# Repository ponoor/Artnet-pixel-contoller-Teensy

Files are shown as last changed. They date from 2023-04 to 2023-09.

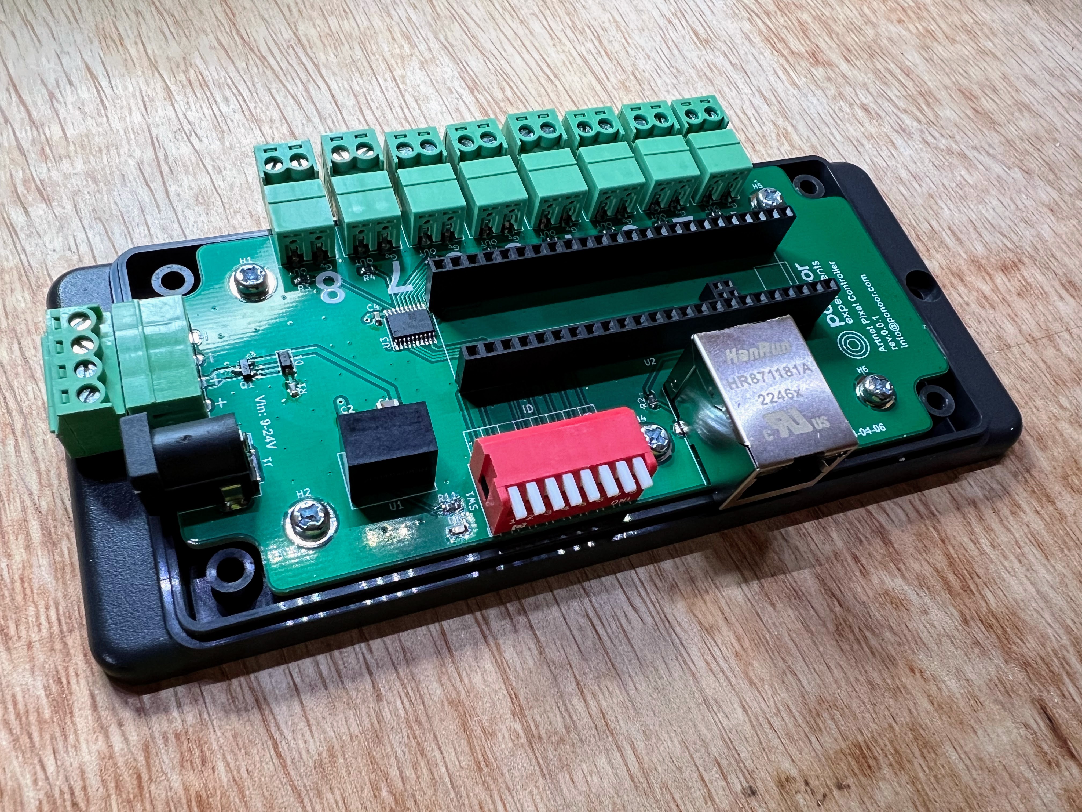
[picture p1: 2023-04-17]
Artnet_pixel_controller_Teensy-hardware/production_data/prototype_Assembled.jpg

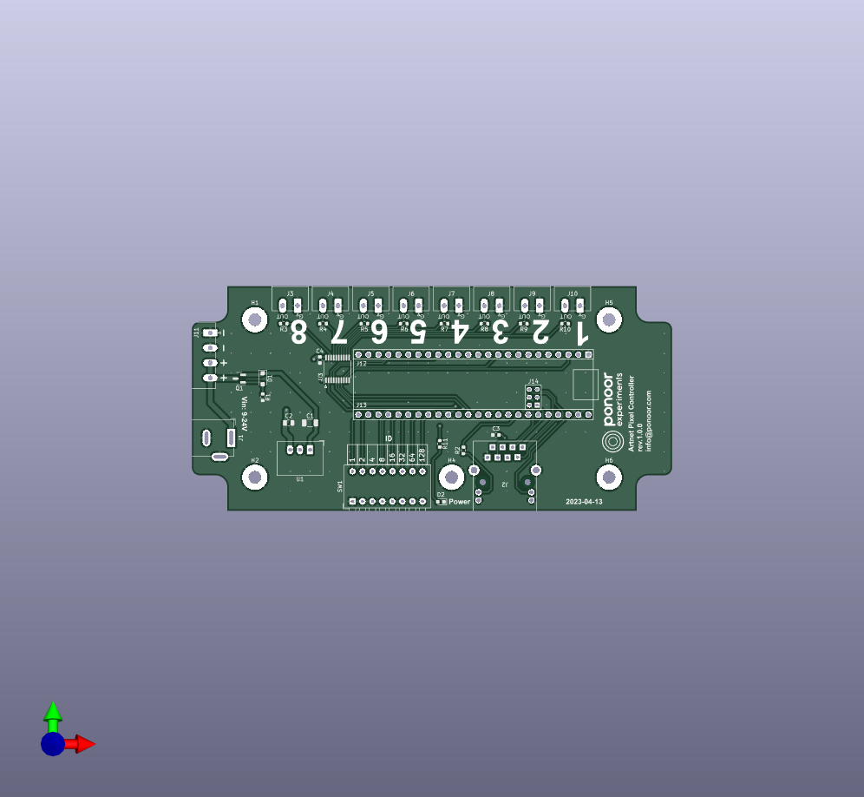
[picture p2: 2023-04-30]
Artnet_pixel_controller_Teensy-hardware/Artnet_pixel_controller_Teensy-hardware.png

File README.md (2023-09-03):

# Artnet-pixel-contoller-Teensy
A simple addressable LED controller with Art-Net.

We choose Teensy4.1 to reduce components around Ethernet. It is bit too luxury for this application but still much cheaper than serious commercial pixel controllers.

- Firmware by niimi
- Hardware by kanta



<!--
<img src="https://github.com/ponoor/Artnet-pixel-contoller-Teensy/assets/1097902/cb70d5fd-e741-4c89-b13c-3c2e43a0f1bb" width="40%" /><img src="https://github.com/ponoor/Artnet-pixel-contoller-Teensy/assets/1097902/271e32cb-7cf3-4a00-a239-2e03ac957660" width="40%" />
-->



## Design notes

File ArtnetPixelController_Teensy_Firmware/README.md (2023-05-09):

# デバイス設定項目
- network
    - ip i i i i
    - gateway i i i i
    - subnet i i i i
    - mac i i i i i i
    - ipAddId i(b)
    - macAddId i(b)
- artnet
    - port i
    - net i
    - subnet i
    - universe i
- osc
    - dstPort i
    - dstIp i i i i
    - srcPort i
    - dstPortAddId i(b)
- led
    - numPixels i
    - protocol i
    - colorOrder i
    - initTest i(b)
## デバイス設定のOSC送り方
/config/network/ip 10 0 0 0
のように送ると値を保存してリセット後に適応される
## colorOrderとは
```
OctoWS2811.h:39
#define WS2811_RGB	0	// The WS2811 datasheet documents this way
#define WS2811_RBG	1
#define WS2811_GRB	2	// Most LED strips are wired this way
#define WS2811_GBR	3
#define WS2811_BRG	4
#define WS2811_BGR	5
```
## protocolとは
```
OctoWS2811.h:70
#define WS2811_800kHz 0x00	// Nearly all WS2811 are 800 kHz
#define WS2811_400kHz 0x40	// Adafruit's Flora Pixels
#define WS2813_800kHz 0x80	// WS2813 are close to 800 kHz but has 300 us frame set delay
```
# その他OSCコマンド
## /rst
リセットする。シリアルをつなげてると起動しないxx
## /print
シリアルにconfigの値を出力する
## /ping
/pongをかえす
## /setDstIp
oscの送信先アドレスをすぐに変えるが保存はされない
## /ledTest
r g b

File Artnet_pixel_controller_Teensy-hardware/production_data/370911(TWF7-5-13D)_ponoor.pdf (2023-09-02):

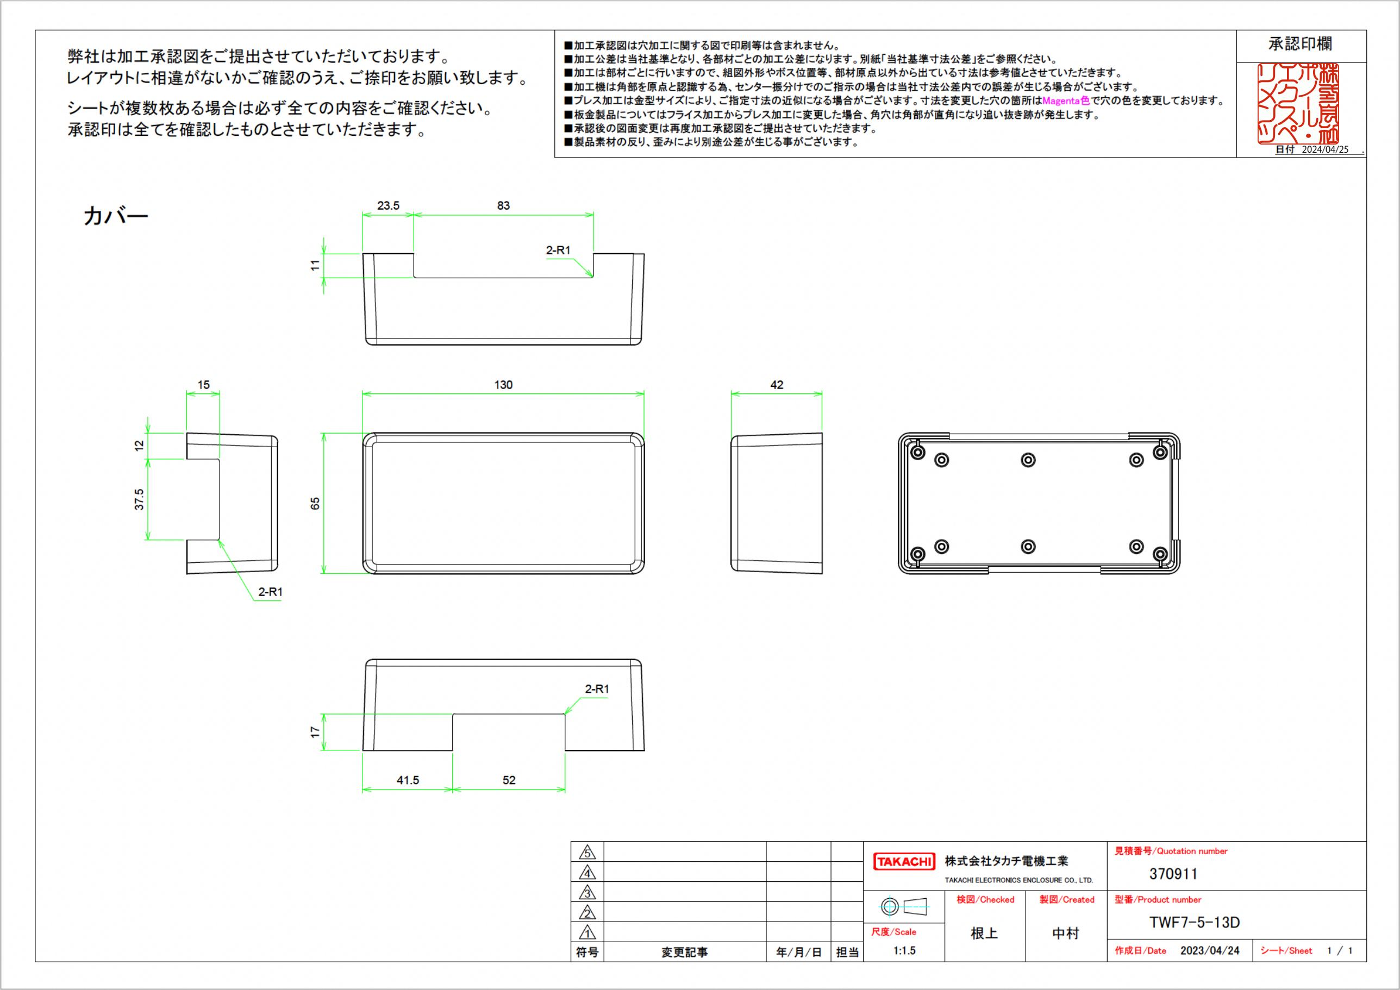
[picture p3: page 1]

2024/04/25

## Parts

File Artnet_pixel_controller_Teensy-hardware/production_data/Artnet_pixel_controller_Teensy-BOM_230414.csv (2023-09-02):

# | Name | Value | Description | Package | Manufacture | MPN | Qty | Ref | SMT | THT
1 | MLCC | 10uF/50V | 10uF / 20% / 50V / X5R | C1206 | Samsung Electro-Mechanics | CL31A106KBHNNNE | 1 | C1 | 1
2 | MLCC | 10uF/10V | 10uF / 20% / 10V / X5R | C0805 | Samsung Electro-Mechanics | CL21A106KOQNNNG | 1 | C2 | 1
3 | MLCC | 100nF/50V | 100nF / 20% / 50V / X5R | C0603 | Walsin Tech Corp | 0603B104K500CT | 2 | C3, C4 | 2
4 | Zener Diode | 5.1V | 350mW 5.1V | SOD-123F | Jiangsu Changjing Electronics Technology Co., Ltd. | BZT52C5V1 | 1 | D1 | 1
5 | LED | Green | general LED green | LED0603 | Everlight Elec | 19-213/GHC-YR1S2M/3T | 1 | D2 | 1
6 | DC Barrel Jack | DC Power receptacle | 5A 2.0mm 6.2mm | Connector_BarrelJack:BarrelJack_GCT_DCJ200-10-A_Horizontal | XKB Connectivity | DC-005-5A-2.0 | 1 | J1 |  | 1
7 | RJ45 Jack with Magnetics | HR871181A |  | HR871181A | Hanrun | HR871181A | 1 | J2 |  | 1
8 | 3.81mm connector | 2 Pins | 3.81mm Pluggable System Terminal Block | Push-Pull,P=3.81mm | Ningbo Kangnex Elec | WJ15EDGRC-3.81-2P | 8 | J3, J4, J5, J6, J7, J8, J9, J10 |  | 8
9 | 3.81mm connector | 4 Pins | 3.81mm Pluggable System Terminal Block | Push-Pull,P=3.81mm | Ningbo Kangnex Elec | WJ15EDGRC-3.81-4P | 1 | J11 |  | 1
10 | Female Headers |  | Straight 1x24P 8.5mm Top 24 Square Holes | P=2.54mm | XKB Connectivity | X6511FV-24-C85D32 | 2 | J12, J13 |  | 2
11 | Female Headers |  | Straight 2x3P 4.3mm Top 6 Square Holes | P=2mm | HCTL | PM200-2-03-Z-4.3 | 1 | J14 |  | 1
12 | P-MOSFET | AO3401A | 30V 4.4A | SOT-23 | Yangzhou Yangjie Elec Tech | YJL3401A | 1 | Q1 | 1
13 | Resistor | 10k | 5% 1/10W | R0603 | YAGEO | RC0603JR-0710KL | 2 | R1, R11 | 2
14 | Resistor | 220 | 5% 1/10W | R0603 | YAGEO | RC0603JR-07220RL | 1 | R2 | 1
15 | Resistor | 470 | 5% 1/10W | R0603 | YAGEO | RC0603JR-07470RL | 8 | R3, R4, R5, R6, R7, R8, R9, R10 | 8
16 | DIP Switches | 8P, Side Sw | SPST Red Piano 8 keys DIP Switches | DIP16 | Cixi Tonver Elec | VPG/S-08HG-R | 1 | SW1 |  | 1
17 | Power Modules | 5V 500mA | 6.5V~36V input DC-DC |  | MORNSUN Guangzhou S& T | K7805-500R3 | 1 | U1 |  | 1
18 | Octal BUS Transceivers, 3-State outputs | 74HC245 | Buffer/Driver/Transceiver | TSSOP-20 | Wuxi I-core Elec | AiP74HCT245TA20.TR | 1 | U3 | 1
 |  |  |  |  |  | SUM: | 35 |  | 19 | 16

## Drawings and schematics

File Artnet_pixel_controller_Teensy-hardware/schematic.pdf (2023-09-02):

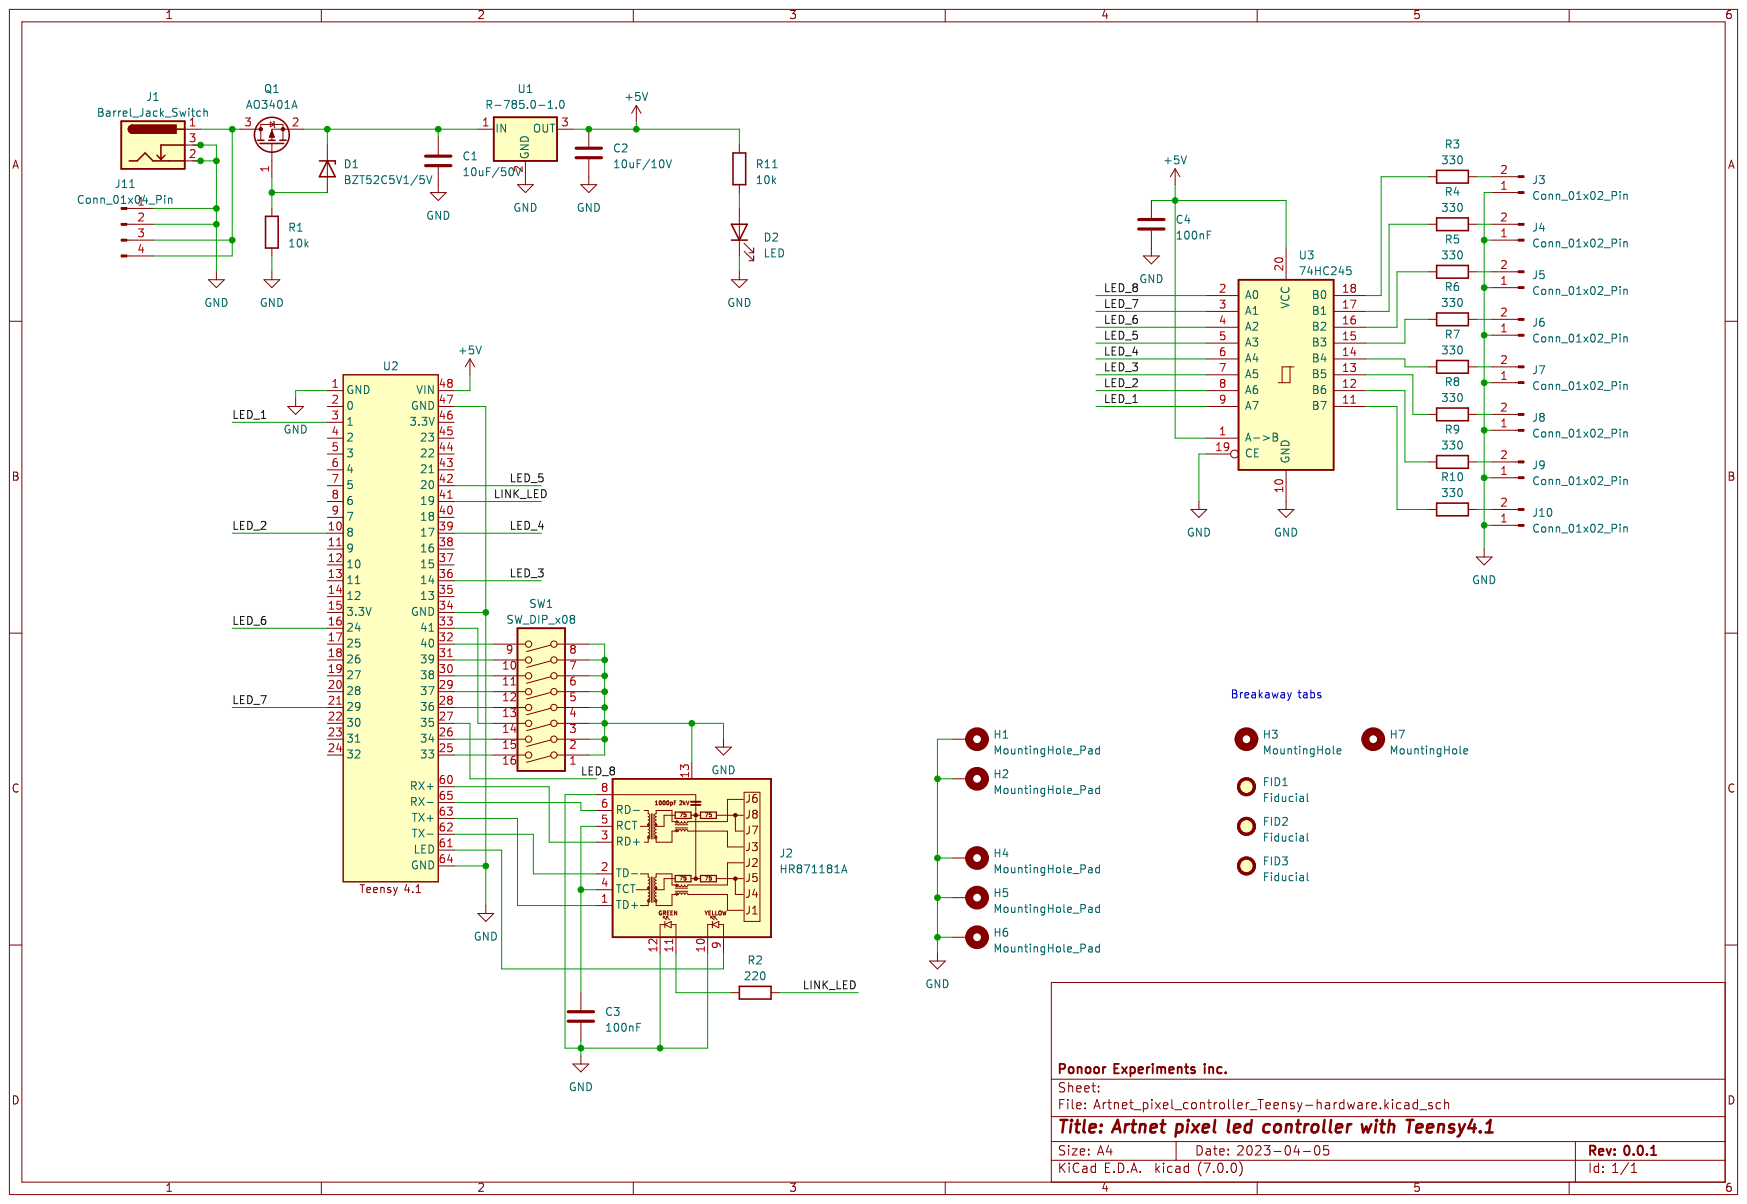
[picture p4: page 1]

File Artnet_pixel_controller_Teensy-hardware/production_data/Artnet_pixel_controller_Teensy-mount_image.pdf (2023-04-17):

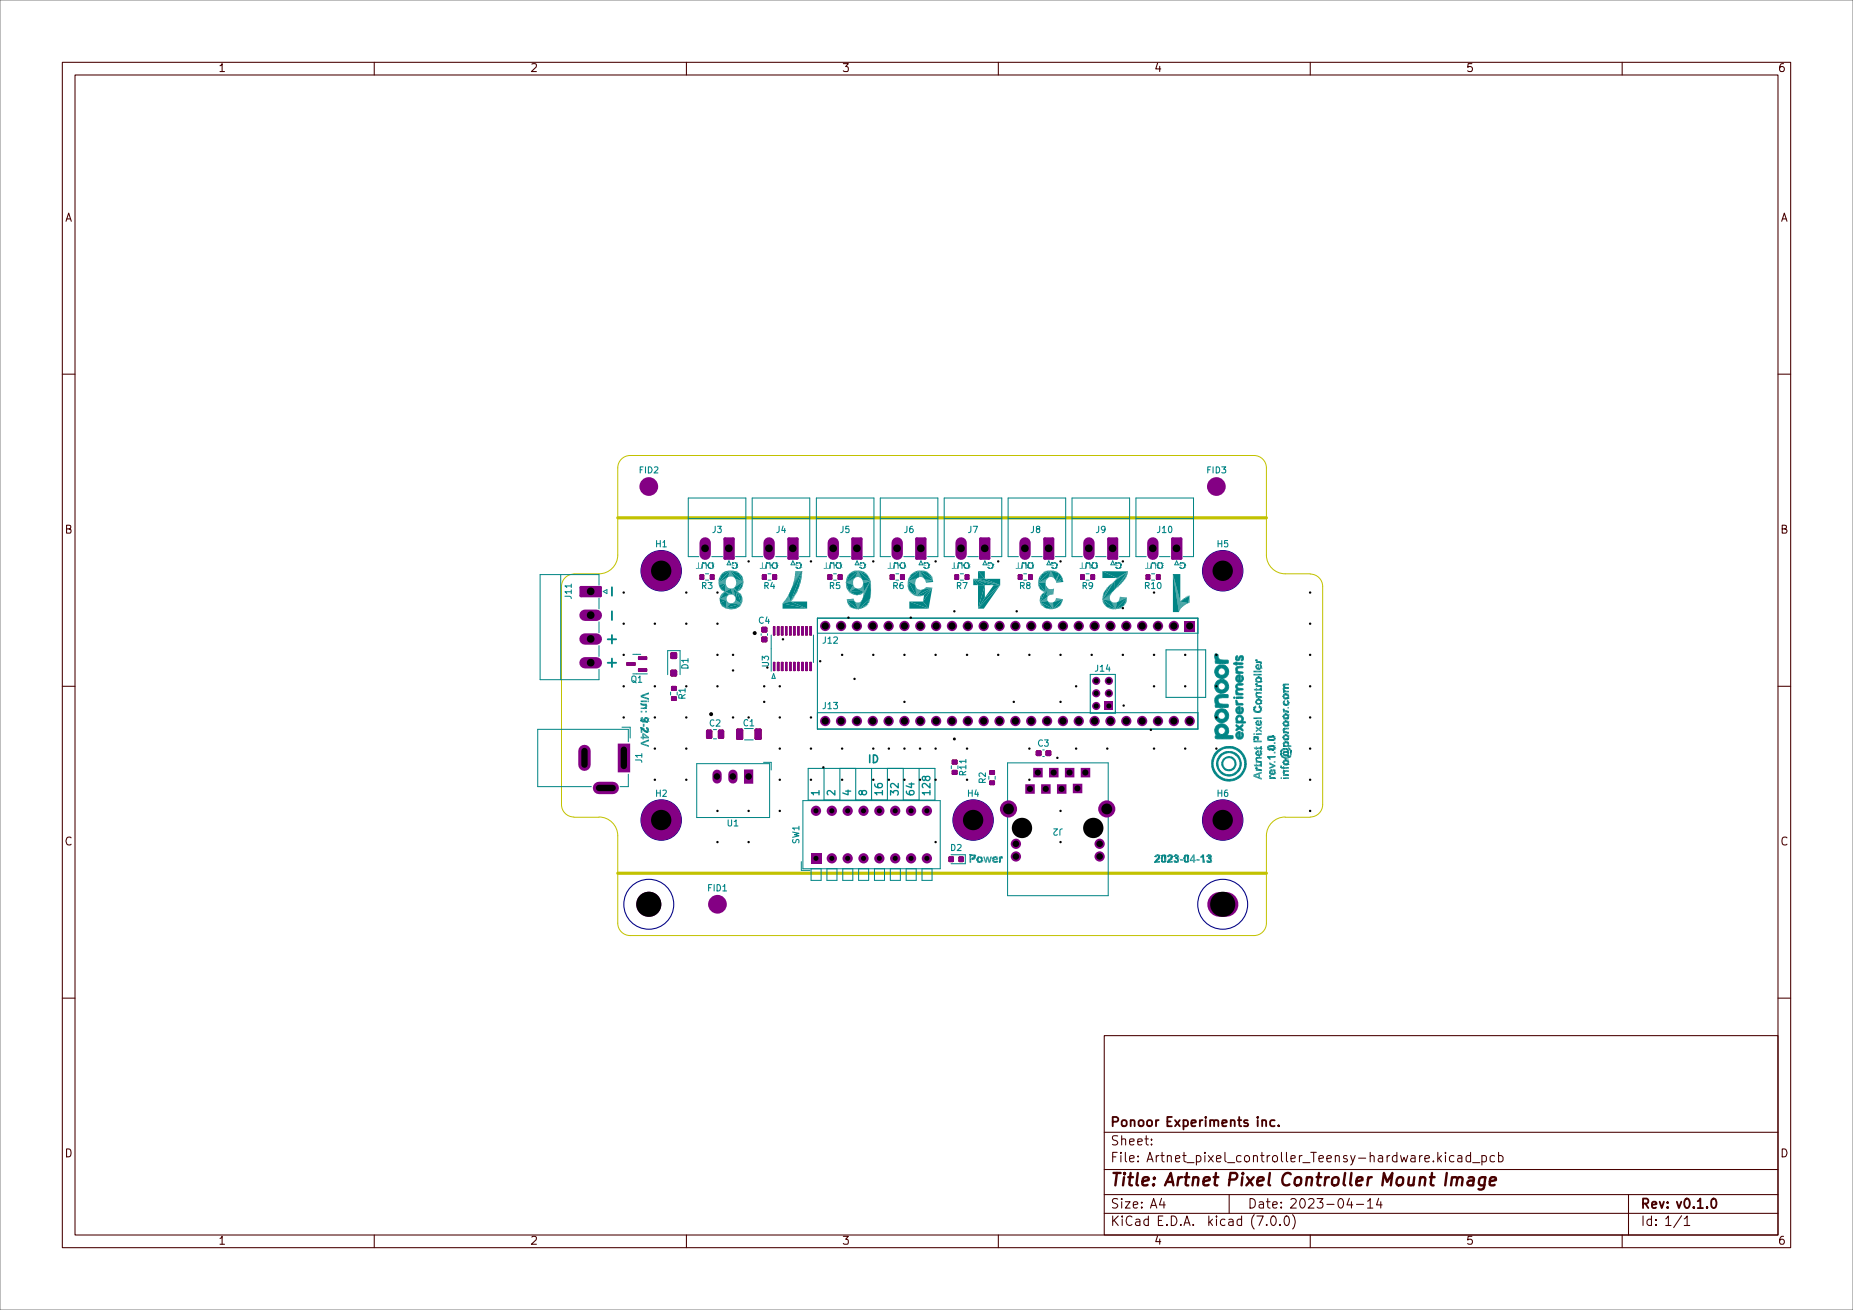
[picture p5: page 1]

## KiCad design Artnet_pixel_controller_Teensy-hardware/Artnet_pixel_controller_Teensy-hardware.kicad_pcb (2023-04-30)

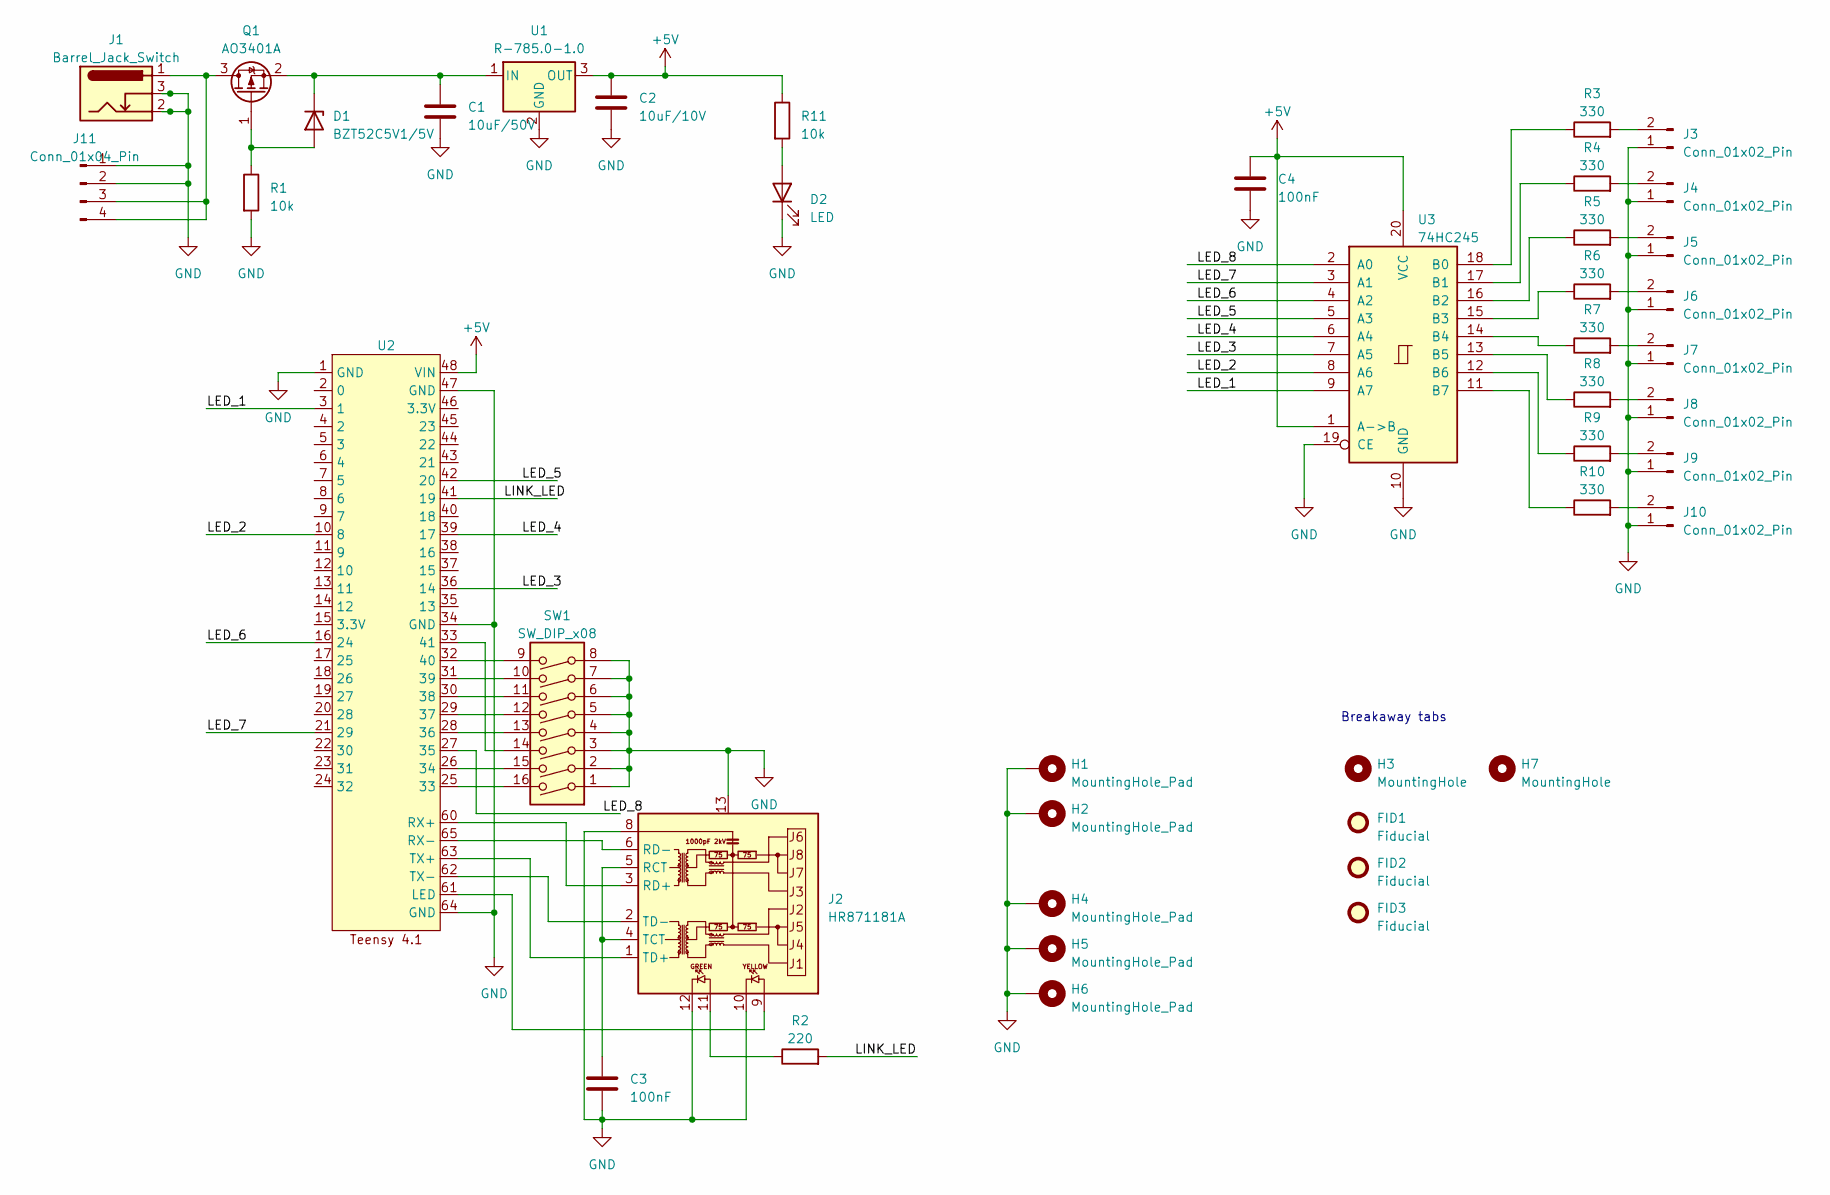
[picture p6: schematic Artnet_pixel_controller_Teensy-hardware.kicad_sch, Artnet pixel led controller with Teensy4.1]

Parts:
C1: 10uF/50V; C_1206_3216Metric
C2: 10uF/10V; C_0805_2012Metric
C3, C4: 100nF; C_0603_1608Metric
D1: BZT52C5V1/5V; D_SOD-123F
D2: LED; LED_0603_1608Metric
FID1, FID2, FID3: Fiducial; Fiducial_1mm_Mask3mm
H1, H2, H4, H5, H6: MountingHole_Pad; MountingHole_3.2mm_M3_Pad
H3, H7: MountingHole; MountingHole_4mm
J1: Barrel_Jack_Switch; BarrelJack_GCT_DCJ200-10-A_Horizontal
J2: HR871181A
J3, J4, J5, J6, J7, J8, J9, J10: Conn_01x02_Pin; PhoenixContact_MC_1,5_2-G-3.81_1x02_P3.81mm_Horizontal
J11: Conn_01x04_Pin; PhoenixContact_MC_1,5_4-G-3.81_1x04_P3.81mm_Horizontal
Q1: AO3401A; SOT-23
R1, R11: 10k; R_0603_1608Metric
R2: 220; R_0603_1608Metric
R3, R4, R5, R6, R7, R8, R9, R10: 330; R_0603_1608Metric
SW1: SW_DIP_x08; SW_DIP_SPSTx08_Piano_10.8x21.88mm_W7.62mm_P2.54mm
U1: R-785.0-1.0; Converter_DCDC_RECOM_R-78E-0.5_THT
U2: Teensy41_bothside+ETH
U3: 74HC245; TSSOP-20_4.4x6.5mm_P0.65mm

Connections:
+5V: C2.1, C4.1, R11.1, U1.3 (OUT), U2.48 (VIN), U3.1 (A->B), U3.20 (VCC)
/LED_1: U2.3 (1), U3.9 (A7)
/LED_2: U2.10 (8), U3.8 (A6)
/LED_3: U2.36 (14), U3.7 (A5)
/LED_4: U2.39 (17), U3.6 (A4)
/LED_5: U2.42 (20), U3.5 (A3)
/LED_6: U2.16 (24), U3.4 (A2)
/LED_7: U2.21 (29), U3.3 (A1)
/LED_8: U2.27 (35), U3.2 (A0)
/LINK_LED: R2.2, U2.41 (19)
GND: C1.2, C2.2, C3.2, C4.2, D2.1 (K), H1.1, H2.1, H4.1, H5.1, H6.1, J1.2, J1.3, J2.8, J2.10, J2.12, J2.13, J3.1, J4.1, J5.1, J6.1, J7.1, J8.1, J9.1, J10.1, J11.1, J11.2, R1.2, SW1.1, SW1.2, SW1.3, SW1.4, SW1.5, SW1.6, SW1.7, SW1.8, U1.2 (GND), U2.1 (GND), U2.34 (GND), U2.47 (GND), U2.64 (GND), U3.10 (GND), U3.19 (CE); also elsewhere on the board
unnamed: D1.2 (A), Q1.1 (G), R1.1
unnamed: C1.1, D1.1 (K), Q1.2 (S), U1.1 (IN)
unnamed: D2.2 (A), R11.2
unnamed: J2.11, R2.1
unnamed: C3.1, J2.4 (TCT), J2.5 (RCT)
unnamed: J2.3 (RD+), U2.60 (RX+)
unnamed: J2.6 (RD-), U2.65 (RX-)
unnamed: J2.1 (TD+), U2.63 (TX+)
unnamed: J2.2 (TD-), U2.62 (TX-)
unnamed: J3.2, R3.2
unnamed: J4.2, R4.2
unnamed: J5.2, R5.2
unnamed: J6.2, R6.2
unnamed: J7.2, R7.2
unnamed: J8.2, R8.2
unnamed: J9.2, R9.2
unnamed: J10.2, R10.2
unnamed: J1.1, J11.3, J11.4, Q1.3 (D)
unnamed: SW1.16, U2.25 (33)
unnamed: SW1.15, U2.26 (34)
unnamed: SW1.13, U2.28 (36)
unnamed: SW1.12, U2.29 (37)
unnamed: SW1.11, U2.30 (38)
unnamed: SW1.10, U2.31 (39)
unnamed: SW1.9, U2.32 (40)
unnamed: SW1.14, U2.33 (41)
unnamed: J2.9, U2.61 (LED)
unnamed: R3.1, U3.18 (B0)
unnamed: R4.1, U3.17 (B1)
unnamed: R5.1, U3.16 (B2)
unnamed: R6.1, U3.15 (B3)
unnamed: R7.1, U3.14 (B4)
unnamed: R8.1, U3.13 (B5)
unnamed: R9.1, U3.12 (B6)
unnamed: R10.1, U3.11 (B7)

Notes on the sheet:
Breakaway tabs

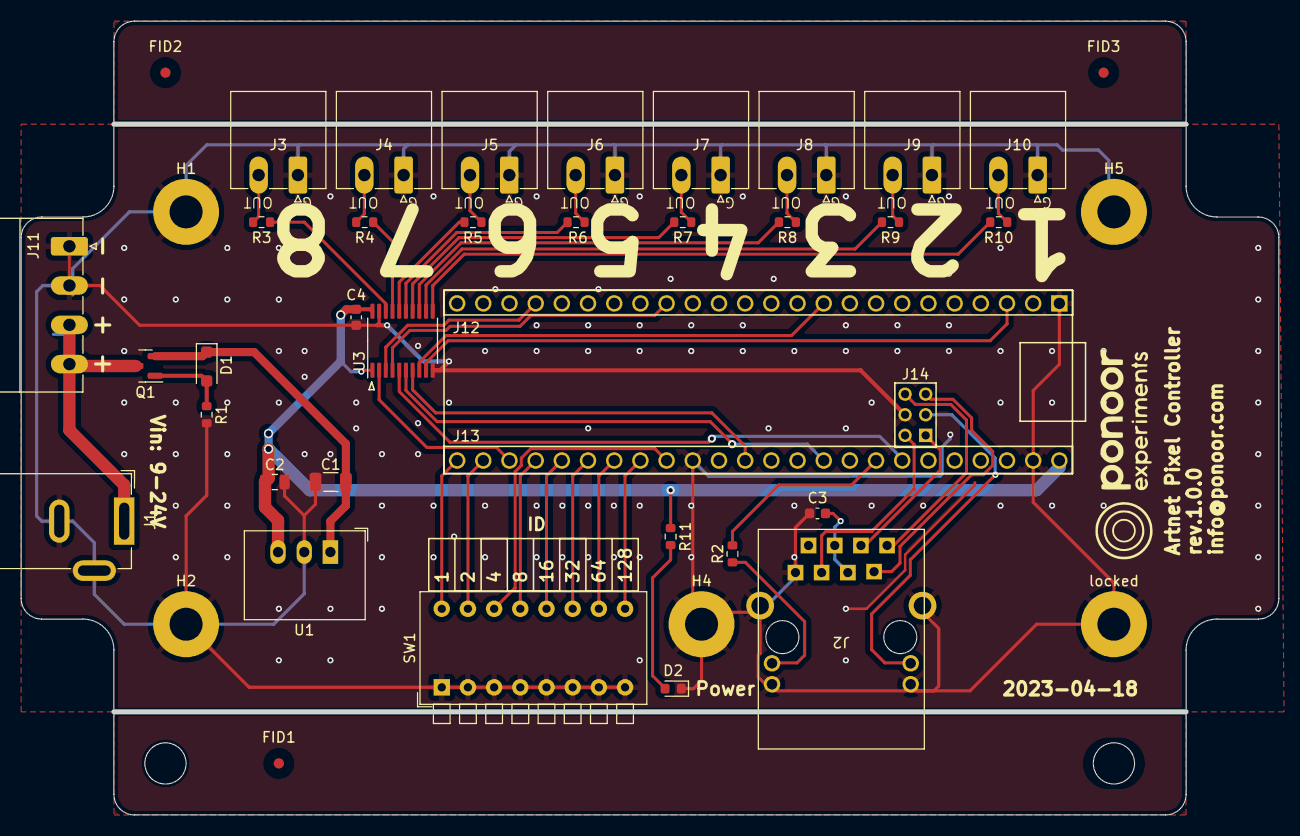
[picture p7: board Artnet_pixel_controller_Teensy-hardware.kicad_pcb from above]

Board: 2 copper layers, 122.0 x 77.0 mm, 43 parts (0 on the bottom side), 46 nets.

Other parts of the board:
locked: MountingHole_Pad; MountingHole_3.2mm_M3_Pad

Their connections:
GND: locked.1; also elsewhere on the board

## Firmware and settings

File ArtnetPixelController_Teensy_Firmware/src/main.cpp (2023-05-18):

#include <Arduino.h>

#include <NativeEthernet.h>
#include <NativeEthernetUdp.h>

#include "ApcConfig.h"
#include "ApcId.h"
#include "ApcArtnet.h"
#include "ApcOsc.h"
// #include "ApcLed.h"
#include "ApcLedSerial.h"

// #define RESTART_ADDR       0xE000ED0C
// #define READ_RESTART()     (*(volatile uint32_t *)RESTART_ADDR)
// #define WRITE_RESTART(val) ((*(volatile uint32_t *)RESTART_ADDR) = (val))

void convertFromJson(JsonVariantConst src, IPAddress& dst) {
  dst.fromString(src.as<const char*>());
}
bool canConvertFromJson(JsonVariantConst src, IPAddress& dst) {
  return dst.fromString(src.as<const char*>());
}
apc::Config config;
apc::Id id;
apc::Artnet artnet;
apc::Osc osc;
apc::LedSerial led;

void onDmxFrame(uint16_t universe, uint16_t length, uint8_t sequence,
                uint8_t* data, IPAddress remoteIP);
void onSync(IPAddress remoteIP);
void onNonSync();

void onReceiveRst();
void onReceiveLedTest();
void onReceivePrint();
void onReceiveClearConfig();
void onReceiveConfigInt(const char* category, const char* name, int value);
void onReceiveConfigIntArray(const char* category, const char* name, int* value, size_t size);
void onReceiveConfigIpaddress(const char* category, const char* name, IPAddress value);

void printDeviceSetting();
void printIp(const char* name, IPAddress ip);

uint8_t universePerStrip;
bool bSerialOpen = false;
bool bLink = false;
void setup() {
    Serial.begin(115200);
    // while (! Serial); 
    delay(1000);
    Serial.println("program start");
    pinMode(apc::variables::linkPin, OUTPUT);

    config.init(0, 1024);
    id.init();

    uint8_t deviceId = id.getId();

    uint8_t mac[6];
    for (auto i = 0; i < 6; i ++) {
        mac[i] = config.json["network"]["mac"][i];
    }
    if (config.json["network"]["macAddId"].as<bool>()) {
        mac[5] += deviceId;
    }
    IPAddress ip = config.json["network"]["ip"];
    if (config.json["network"]["ipAddId"].as<bool>()) {
        ip[3] += deviceId;
    }

    Ethernet.begin(
        mac,
        ip, 
        config.json["network"]["gateway"], 
        config.json["network"]["gateway"], 
        config.json["network"]["subnet"]);

    universePerStrip = ceil(config.json["led"]["numPixels"].as<uint16_t>() / 170.0f);
    
    artnet.init(config.json["artnet"]["port"], 
        ip,
        config.json["network"]["subnet"],
        config.json["artnet"]["net"], 
        config.json["artnet"]["subnet"], 
        config.json["artnet"]["universe"],
        config.json["artnet"]["fps"],
        (bool)config.json["artnet"]["foceSync"]);
    
    artnet.setArtDmxCallback(onDmxFrame);
    artnet.setArtSyncCallback(onSync);
    artnet.setNonSyncCallback(onNonSync);

    int dstPort = config.json["osc"]["dstPort"];
    if (config.json["osc"]["dstPortAddId"]) {
        dstPort += deviceId;
    }
    osc.init(config.json["osc"]["srcPort"], config.json["osc"]["dstIp"], dstPort);
    osc.setRstCallback(onReceiveRst);
    osc.setPrintCallback(onReceivePrint);
    osc.setClearConfigCallback(onReceiveClearConfig);
    osc.setLedTestCallback(onReceiveLedTest);
    osc.setConfigCallbackInt(onReceiveConfigInt);
    osc.setConfigCallbackIntArray(onReceiveConfigIntArray);
    osc.setConfigCallbackIpaddress(onReceiveConfigIpaddress);

    led.init(
        (int)config.json["led"]["numPixels"],
        (uint8_t)config.json["led"]["colorOrder"],
        (uint8_t)config.json["led"]["protocol"]);
    
    if (config.json["led"]["initTest"].as<bool>()) {
        led.initTest();
    }
}

void loop() {
    artnet.update();
    osc.update();

    if(Ethernet.linkStatus() == LinkON) {
        if (!bLink) {
            bLink = true;
            digitalWrite(apc::variables::linkPin, HIGH);
        }
    } else {
        if (bLink) {
            bLink = false;
            digitalWrite(apc::variables::linkPin, LOW);
        }
    }

    if (Serial) {
        if (!bSerialOpen) {
            bSerialOpen = true;
            printDeviceSetting();
        }
    } else {
        if (bSerialOpen) {
            bSerialOpen = false;
        }
    }
    // put your main code here, to run repeatedly:
}

// uint32_t dmxTimestamp = 0;
// uint32_t syncTimestamp = 0;

void onDmxFrame(
    uint16_t universe, 
    uint16_t length, 
    uint8_t sequence,
    uint8_t* data, 
    IPAddress remoteIP) {

    uint8_t stripIndex = universe / universePerStrip;
    uint8_t universeIndex = universe % universePerStrip;

    // Serial.printf("on dmx frame: {uni: %d, len: %d, seq: %d}\n", universe, length, sequence);
    // Serial.print(", strip index: ");
    // Serial.print(stripIndex);
    // Serial.print(", univIndex: ");
    // Serial.print(universeIndex);
    // Serial.println("}");
    
    led.setPixels(stripIndex, universeIndex * 170, data, length);
    // if (universe == 0) {
    //     uint32_t now = millis();
    //     Serial.printf("dmx time: %d, delta: %d\t", now, now - dmxTimestamp);
    //     dmxTimestamp = now;
    // }
}
//on dmx frame: { uni: 31, len: 512, strip index: 7, univIndex: 3}
void onSync(IPAddress remoteIP) { 
    // Serial.println("on sync: ");
    led.show();
    // uint32_t now = millis();
    // Serial.printf("sync time: %d, delta: %d\n", now, now - syncTimestamp);
    // syncTimestamp = now;
}
void onNonSync() {
    led.show();
}

void onReceiveRst() {
    // _restart_Teensyduino_();
    // WRITE_RESTART(0x5FA0004);
    // SCB_AIRCR = 0x05FA0004;
    SCB_AIRCR = 0x05FA0004;
    asm volatile ("dsb");
    // asm volatile ("BKPT 254");
}
void onReceiveLedTest() {
    led.initTest();
}
void onReceivePrint() {
    printDeviceSetting();
}
void onReceiveClearConfig() {
    config.clear();
}
void onReceiveConfigInt(const char* category, const char* name, int value) {
    bool result = false;
    if (config.setValue(category, name, value)) {
        config.write();
        result = true;
    }
    Serial.printf("cat: %s, name: %s, value: %d, result: %d\n", category, name, value, result);
    osc.sendConfigReply(category, name, result);
}
void onReceiveConfigIntArray(const char* category, const char* name, int* value, size_t size) {
    bool result = false;
    if (config.setValue(category, name, value, size)) {
        config.write();
        result = true;
    }
    // Serial.printf("cat: %s, name: %s, value: %d, result: %d\n", category, name, value, result);
    // for (size_t i; i < size; i ++) {

    // }
    osc.sendConfigReply(category, name, result);
}
void onReceiveConfigIpaddress(const char* category, const char* name, IPAddress value) {
    // Serial.printf("cat: %s, name: %s, value: %d.%d.%d.%d\n", category, name, value[0], value[1], value[2], value[3]);
    bool result = false;
    if (config.setValue(category, name, value)) {
        config.write();
        result = true;
    }
    osc.sendConfigReply(category, name, result);
}
void onReceiveConfigFloat(const char* category, const char* name, float value) {
    bool result = false;
    if (config.setValue(category, name, value)) {
        config.write();
        result = true;
    }
    Serial.printf("cat: %s, name: %s, value: %f, result: %d\n", category, name, value, result);
    osc.sendConfigReply(category, name, result);
}
void printDeviceSetting() {
    Serial.print("============================\n");
    Serial.printf("device id: %d\n", id.getId());
    printIp("ip", Ethernet.localIP());
    printIp("subnet", Ethernet.subnetMask());
    printIp("gateway", Ethernet.gatewayIP());
    uint8_t mac[6];
    Ethernet.MACAddress(mac);
    Serial.printf("mac: %d:%d:%d:%d:%d:%d\n", mac[0], mac[1], mac[2], mac[3], mac[4], mac[5]);
    Serial.print("============================\n");
    config.print(true);
}

void printIp(const char* name, IPAddress ip) {
    Serial.printf("%s: %d.%d.%d.%d\n", name, ip[0], ip[1], ip[2], ip[3]);
}

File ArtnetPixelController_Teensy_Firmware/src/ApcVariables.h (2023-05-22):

#ifndef APC_VARIABLES_H
#define APC_VARIABLES_H
#include <Arduino.h>
#include <OctoWS2811.h>

namespace apc {
    namespace variables {
        namespace defaultSettings {
            namespace network {
                static const IPAddress ip(10, 0, 0, 0);
                static const IPAddress gateway(10, 0, 0, 200);
                static const IPAddress subnet(255, 255, 255, 0);
                static const uint8_t mac[6] = {0x60, 0x95, 0xCE, 0x10, 0x07, 0x00};//60:95:CE:10:07:xx 
                static const uint8_t ipAddId = 1;
                static const uint8_t macAddId = 1;
                
            }
            namespace artnet {
                static const int port = 6454;
                static const int net = 0;
                static const int subnet = 0;
                static const int universe = 0;
                static const float fps = 44.0f;
                static const uint8_t forceSync = 0;
            }
            namespace osc {
                static const int dstPort = 50000;
                static const IPAddress dstIp(10, 0, 0, 201);
                static const int srcPort = 50000;
                static const uint8_t dstPortAddId = 0;
            }
            namespace led {
                static const int numPixels = 680;
                static const uint8_t protocol = WS2811_800kHz;
                static const uint8_t colorOrder = WS2811_RGB;
                static const uint8_t initTest = 1;
            }
        }
        static const int numStrips = 8;
        static const uint8_t ledPinList[8] = {1, 8, 14, 17, 20, 24, 29, 35};
        static const uint8_t dipPinList[8] = {33, 34, 41, 36, 37, 38, 39, 40};
        static const int maxPixels = 680;
        static const int linkPin = 19;
    }
} // namespace apc

#endif // APC_VARIABLES_H

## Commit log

2023-04-03 Added KiCad project (still empty)
    [Artnet_pixel_controller_Teensy-hardware.kicad_pcb, Artnet_pixel_controller_Teensy-hardware.kicad_sch]
2023-04-04 回路図と基板上の部品配置を大雑把に置いた
    [Artnet_pixel_controller_Teensy-hardware.kicad_pcb, Artnet_pixel_controller_Teensy-hardware.kicad_sch]
2023-04-05 WS2812Serial用のピン配置に変更
    [Artnet_pixel_controller_Teensy-hardware.kicad_pcb, Artnet_pixel_controller_Teensy-hardware.kicad_sch]
2023-04-06 プロト基板入稿データ
    [Artnet_pixel_controller_Teensy-hardware-B_Cu.gbr, Artnet_pixel_controller_Teensy-hardware-B_Mask.gbr, Artnet_pixel_controller_Teensy-hardware-B_Paste.gbr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]
2023-04-12 動作テスト用に使ったコードを追加
2023-04-13 gerber data v1.0.0
    [Artnet_pixel_controller_Teensy-hardware-B_Cu.gbr, Artnet_pixel_controller_Teensy-hardware-B_Mask.gbr, Artnet_pixel_controller_Teensy-hardware-B_Paste.gbr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]
2023-04-17 LED出力の番号を入れ替え
    [Artnet_pixel_controller_Teensy-BOM_230414.xlsx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]
2023-04-30 PCB fabrication data
    [Artnet_pixel_controller_Teensy-hardware-B_Cu.gbr, Artnet_pixel_controller_Teensy-hardware-B_Mask.gbr, Artnet_pixel_controller_Teensy-hardware-B_Paste.gbr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]
2023-05-08 コミットメント
2023-05-09 oscコマンドを追加して確認した
2023-05-16 sync来なかったら光る
2023-05-16 link led
2023-05-16 oscで設定をもとに戻す
2023-05-17 ws2812Serialにした
2023-05-18 ファイルの名前を変えた busy実装
2023-09-02 organize files
    [Artnet_pixel_controller_Teensy-BOM_230414.xlsx, Artnet_pixel_controller_Teensy-pos_230414.xlsx]
2023-09-02 include .csv files to the repo
    [Artnet_pixel_controller_Teensy-BOM_230414.csv, Artnet_pixel_controller_Teensy-pos_230414.csv]
